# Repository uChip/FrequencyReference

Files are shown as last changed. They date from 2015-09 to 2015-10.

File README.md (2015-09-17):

Programmable Frequency Reference   
================================  

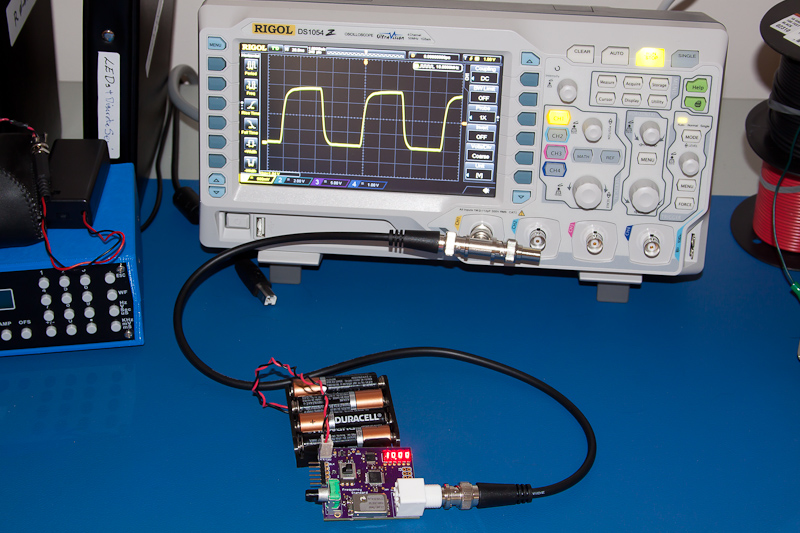
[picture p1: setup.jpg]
  
Screen capture of 10 MHz Frequency Reference signal  

This repository contains the design files and write-up for a Programmable Frequency Reference board based on the RALTRON RTX0230LC*.  The RTX0230LC is a ~1ppm accurate and stable crystal oscillator.  It is temperature compensated and tunable.  The oscillator drives the master clock of an ATmega328 microcontroller which then generates the output frequency by dividing down the master clock.  The ~2Vpp output signal is available on the BNC connector and has been impedance matched to 50 Ohms.

A set of common (and even**) frequencies from 10 MHz down to 152.6 Hz is selectable via a rotary encoder.  As each frequency is selected a representation of that frequency is shown on the display.  The following table shows the frequencies available and the displayed value.
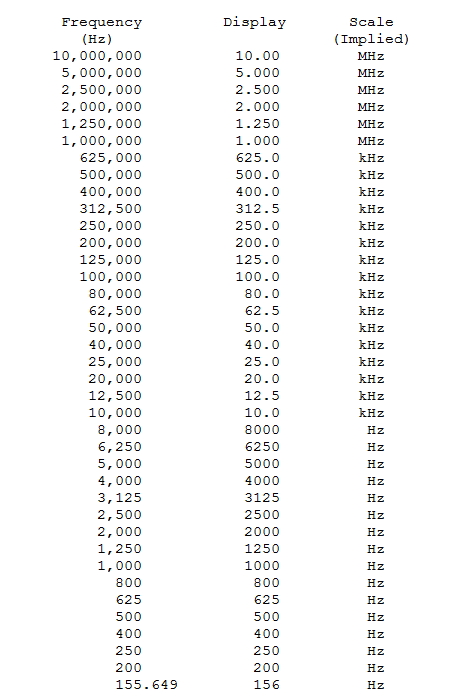
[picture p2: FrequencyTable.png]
Common Frequency Table


NOTE that the display is NOT a measure of the produced frequency.

Within the microcontroller the TCXO clock drives Timer/Counter1.  The Timer/Counter1 is configured to count up until the value matches that in Output Compare Register A (OCR1A) at which point the counter is reset to zero and the output pin OC1A is toggled.  The values for OCR1A are selected from a table when the encoder knob is turned.

Alternatively, pressing the encoder knob will change the mode of the software and instead of choosing from a table, an integer divisor value (0 to 65535) is shown on the display and sent to OCR1A.  The count is incremented or decremented by turning the encoder knob.  The output frequency will be a function of the integer value as follows:

F_OUT = F_CPU / ( 2 * ( OCR1A + 1 ))

Pressing the encoder knob again returns the software to the common frequency mode.

The mode, table value and divisor can also be sent to the microcontroller over USB through the board's FTDI interface.  For details on USB programming, see the document USB_Programming.pdf in this repo.

The firmware folder contains an Arduino sketch and associated library that is source for the microcontroller code.

The next revision of the board will be designed to accomodate other oscillators should the RTX0230LC become unavailable or if even higher precision and stability are required.  Also, the firmware can be used on an "off the shelf" Arduino Uno to create a functional but less accurate frequency generator.  See the file VariationsOnATheme.pdf in this repo for more details.

NOTES  

\* The RALTRON RTX0230LC is a surplus part cheaply available (~$5.50 for 5 pieces at the time of this writing) on ebay. http://www.ebay.com/sch/i.html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

** Mostly.  All but the last are even numbered divisions of the master clock.  The last is the highest possible divisor, 65535, generating the lowest possible*** frequency.

*** Not really.  The firmware configures the timer/counter to be driven by the system clock.  By reconfiguring, the timer/counter could instead be driven by a prescaled clock.  Prescaler values are 1, 8, 64, 256, 1024, allowing for much lower frequency generation if needed.  The prescaler value can be set via the USB interface.

## Order PCBs  

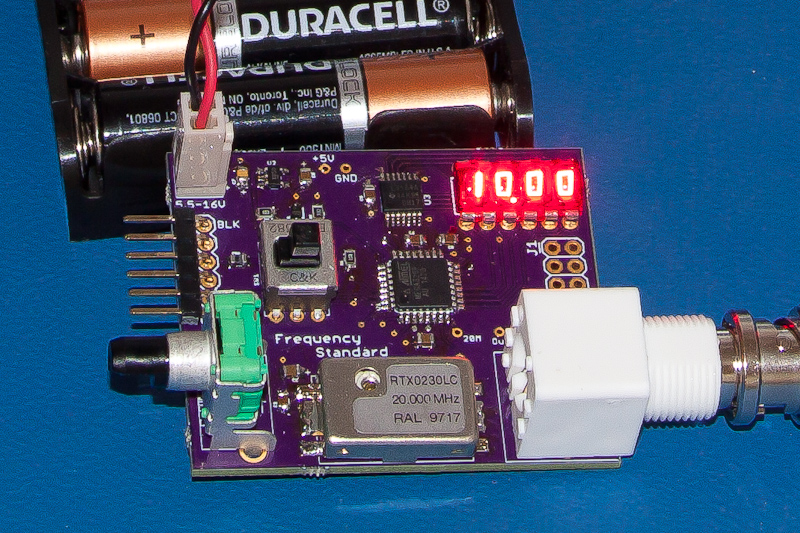
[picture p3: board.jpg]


If there is sufficient interest I will build and calibrate a batch of these to sell.  If you would like one, please contact me.

You can order this PCB directly from OSH Park.  Click on the following link.  
  * Programmable Frequency Reference - https://oshpark.com/shared_projects/a4BIq3K5 

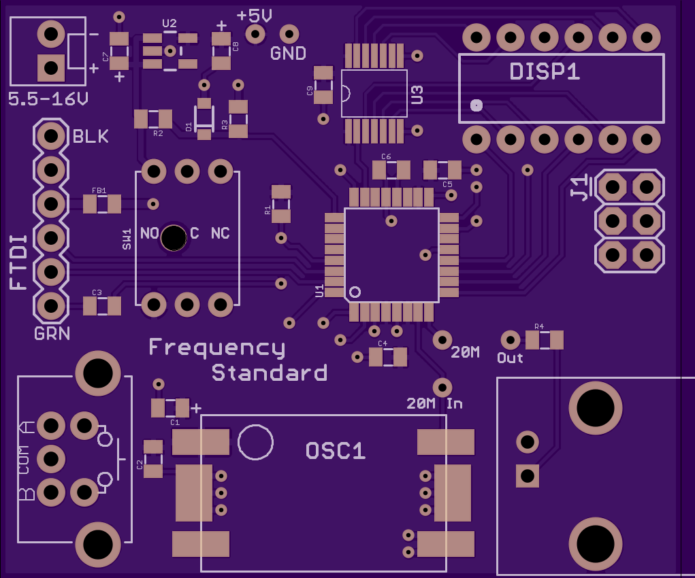
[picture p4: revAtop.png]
PCB Top


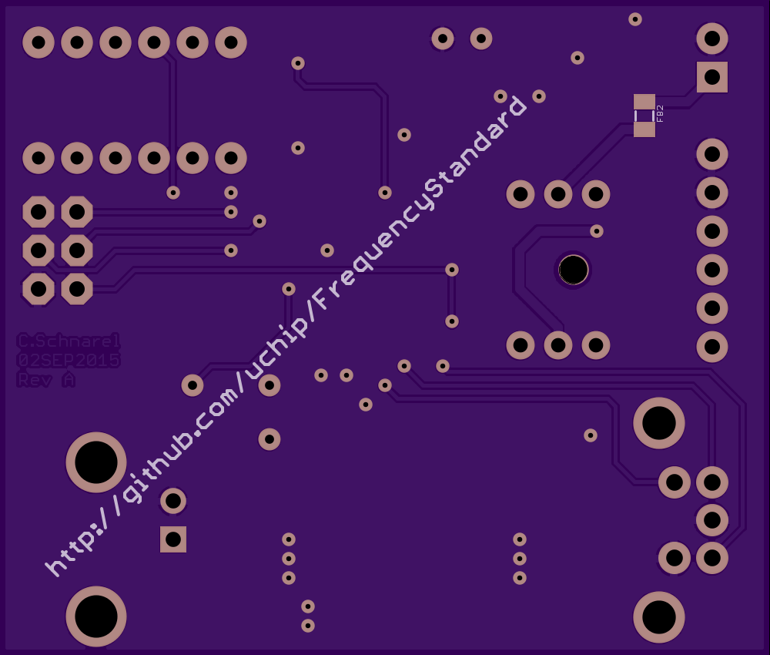
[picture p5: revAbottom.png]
PCB Bottom


See the Bill of Materials (BOM) file for a parts list.  

## Status  
  * Rev A PCB and firmware have been tested to be functional. Rev A is an earlier branch in this repo.  The design has since moved on to add support for other oscillators.
  * Rev B Not yet complete or tested.

## File Formats  

Hardware design files are in "CadSoft EAGLE PCB Design Software" .brd and .sch formats.  A free version of the software can be downloaded from www.cadsoftusa.com. 

The example code is in Arduino .ino format (text).  A free version of the Arduino software can be downloaded from www.arduino.cc. 

Documentation is generally done in Wordpad .rtf and Excel .xlsx.

Viewable versions of layout, schematic and documentation are generally available in common formats such as .pdf, .png, .jpg, .txt, etc.   

## Attributions

While the board layout, circuit design and microcontroller firmware are all my own, the idea for this project grew out of the 3 Dollar Precision Frequency Standard thread started by paulie on EEVBlog forum  http://www.eevblog.com/forum/projects/3-dollar-precision-frequency-standard/  

## Distribution License  

License:
<br /><span xmlns:dct="http://purl.org/dc/terms/" property="dct:title">Programmable Frequency Reference</span> by <a xmlns:cc="http://creativecommons.org/ns#" href="https://github.com/uChip/FrequencyReference" property="cc:attributionName" rel="cc:attributionURL">C.Schnarel</a> is licensed under a <a rel="license" href="http://creativecommons.org/licenses/by-sa/4.0/">Creative Commons Attribution-ShareAlike 4.0 International License</a>.

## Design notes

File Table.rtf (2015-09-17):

Frequency Display Scale
(Hz) (Implied)
10,000,000 10.00 MHz
5,000,000 5.000 MHz
2,500,000 2.500 MHz
2,000,000 2.000 MHz
1,250,000 1.250 MHz
1,000,000 1.000 MHz
625,000 625.0 kHz
500,000 500.0 kHz
400,000 400.0 kHz
312,500 312.5 kHz
250,000 250.0 kHz
200,000 200.0 kHz
125,000 125.0 kHz
100,000 100.0 kHz
80,000 80.0 kHz
62,500 62.5 kHz
50,000 50.0 kHz
40,000 40.0 kHz
25,000 25.0 kHz
20,000 20.0 kHz
12,500 12.5 kHz
10,000 10.0 kHz
8,000 8000 Hz
6,250 6250 Hz
5,000 5000 Hz
4,000 4000 Hz
3,125 3125 Hz
2,500 2500 Hz
2,000 2000 Hz
1,250 1250 Hz
1,000 1000 Hz
800 800 Hz
625 625 Hz
500 500 Hz
400 400 Hz
250 250 Hz
200 200 Hz
155.649 156 Hz

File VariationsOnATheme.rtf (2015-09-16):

Alternatives and Variations

The Frequency Reference is made up of just a few functional blocks connected as shown below.

The heart of the device is the precision oscillator. The final output frequency is an integer division of the oscillator. The output block in this case is merely a resistor and a BNC connector. The divider circuit is an integrated peripheral of the controller. Once the divider is set up by the controller, it operates independently. The controller can change the setup of the divider at any time and does so in response to input.** Input can either be the rotary encoder / switch or the USB/serial port. Note that the controller sends setup information to the divider but does not ever read anything back. The display is driven by the controller and does not rely on the state of the divider.

The precision and stability of the entire circuit depends on the oscillator. The nominal design uses the RTX-230 which actually has pretty good stability considering it costs around a dollar. To make a better reference, choose an oscillator with better specs. Rev-B of the circuit board retains support for the RTX-230 but also allows for oscillators with very good published specifications for, granted, a lot more money. Because most of the circuit is digital, the overall precision of the device increases with the better oscillator. That is, the fact that the rest of the circuit is cheap does not mean that it degrades the better oscillator performance.

Here are a few examples of alternate oscillator parts with increasing accuracy, stability and price. The Raltron part is also shown for comparison. Any of these will work with the Frequency Reference circuit, but not with the Rev-A PCB. I will work to include support for as many of these as I can on the Rev-B PCB (although due to cost, I will not be able to test them all).

Type | MFR | Part # | Initial (+-)ppm | Temp (+-)ppb | Voltage (+-)ppb | Aging (+-)ppb/day | Inclusive (+-)ppm | Over(yrs) | Temp Range | Cost | Supply Voltage | Supply Current max mA
TCXO | Raltron | RTX-230 | Adj | 2500 | 300 | | 1 | 1 | -30-75 | $ 1.10 | 5 | 2
TCXO | Connor-Winfield | M100F-020.0M | 1 | 100 | 200 | 40 | 3.0 | 20 | 0-70 | $ 23.70 | 3.3 | 3.3
TCXO | Connor-Winfield | DOT050F-020.0M | 1 | 50 | 20 | 10 | 4.6 | 15 | 0-70 | $ 39.38 | 3.3 | 10
OCXO | Connor-Winfield | DOC020F-020.0M | 1 | 20 | 20 | 10 | 4.6 | 20 | 0-70 | $ 54.33 | 3.3 | 758
OCXO | Connor-Winfield | OH100-70503CF-020.0M | 0.1 | 5 | 2 | 1 | 0.3 | 20 | -20-70 | $ 115.50 | 3.3 | 970
Prices are from Digi-Key

**Changing frequencies is not phase synchronous. When the change occurs, the clock is stopped, the new divisor (or prescaler) value is programmed, the count is zero’d, then the clock is restarted.

Other Frequencies

The board and software do not really know what frequency they are running at. You could therefore substitute oscillators of other frequencies. The output frequency would scale but otherwise everything would work the same. The maximum frequency oscillator is in the neighborhood of 20MHz. Higher frequencies would be over-clocking the controller, but it will still work up to a point. Lower frequencies are also okay, however the display might start to flicker as the lower clock means a slower controller. The flicker can be fixed by changing the delays in the software. In either case baud rates will need to be scaled for correct serial communications.

As an example, the exact same (source) code will run on a SparkFun Redboard (Arduino Uno clone) which runs at 16MHz and derives its clock from a ceramic resonator rather than a crystal. The software works fine (with degraded accuracy, tempco and jitter), however the frequency table shifts down to the following.

Frequency Display Scale
(Hz) (Implied)
8,000,000 10.00 MHz
4,000,000 5.000 MHz
2,000,000 2.500 MHz
1,600,000 2.000 MHz
1,000,000 1.250 MHz
800,000 1.000 MHz
400,000 500.0 kHz
320,000 400.0 kHz
250,000 312.5 kHz
200,000 250.0 kHz
160,000 200.0 kHz
100,000 125.0 kHz
80,000 100.0 kHz
64,000 80.0 kHz
40,000 50.0 kHz
32,000 40.0 kHz
20,000 25.0 kHz
16,000 20.0 kHz
10,000 12.5 kHz
8,000 10.0 kHz
6,400 8000 Hz
4,000 5000 Hz
3,200 4000 Hz
2,500 3125 Hz
2,000 2500 Hz
1,600 2000 Hz
1,000 1250 Hz
800 1000 Hz
640 800 Hz
400 500 Hz
320 400 Hz
200 250 Hz
160 200 Hz
122.07 153 Hz

Note that the display does not change since it is unrelated to the actual frequency. You can make the display correct (sort of, without more work, decimals will be wrong sometimes) by substituting the following data table in the source.

static uint16_t dispFreq[] = {
8000, // 8,000,000
4000, // 4,000,000
2000, // 2,000,000
1600, // 1,600,000
1000, // 1,000,000
8000, // 800,000
4000, // 400,000
3200, // 320,000
2500, // 250,000
2000, // 200,000
1600, // 160,000
1000, // 100,000
800, // 80,000
640, // 64,000
400, // 40,000
320, // 32,000
200, // 20,000
160, // 16,000
100, // 10,000
8000, // 8,000
6400, // 6,400
4000, // 4,000
3200, // 3,200
2500, // 2,500
2000, // 2,000
1600, // 1,600
1000, // 1,000
800, // 800
640, // 640
400, // 400
320, // 320
200, // 200
160, // 160
122 // 122
};

By further adjusting these tables, oscillators of other frequencies can be accommodated.

Cost

The original intent of the “$3 Frequency Standard” has been compromised by the cost of the rotary encoder, PCB and display circuitry. Still the entire cost remains under $22 total, which is not too bad in my opinion. Here is a cost breakdown of the BOM.

If this is too expensive for you, the cost can be lowered by not populating various parts of the PCB.

You can eliminate the display by not populating DISP1, U3 and C9. The device will operate the same. You can use an external frequency counter to see where you are at.

The device will also operate if you do not populate the rotary encoder. Then user input will need to be supplied over the serial interface.

You can choose to not populate the power switch. Either wire in a cheaper switch or just jumper the NO to C pins on each side. You can choose to not populate the power input connector by just soldering wires in directly (or by powering only off of USB through the FTDI connector). If you only power from USB/FTDI you can choose to not populate the voltage regulator, U2, and associated components, JP1, C7, D1, FB2, R2, & R3.

If you exercise all of these, the cost comes out to be $14.37. You can squeeze out a few more dollars if you forego things like the BNC connector and use cheaper components, but the output signal will suffer.

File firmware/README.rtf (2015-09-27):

Firmware Build Notes
WARNING: THE INSTRUCTIONS BELOW HAVE THE POTENTIAL TO CORRUPT YOUR ARDUINO IDE INSTALLATION. PROCEED AT YOUR OWN PERIL! OF COURSE, IF YOU REALLY MESS THINGS UP YOU CAN ALWAYS UNINSTALL AND REINSTALL THE IDE.
ANOTHER WARNING: I MANAGED TO BRICK THE MICROCONTROLLER EXPERIMENTING WITH THE INSTRUCTIONS BELOW. SEE “Unbricking the Microcontroller” BELOW FOR MORE DETAILS.
NOTE: These instructions were developed and tested using the Arduino 1.6.4 IDE. I have no idea whether they will work for other versions of the IDE.

The Frequency Reference firmware is built using the Arduino IDE, however there are a couple of complications. These complications arise because Arduino generally expects the ATmega328p to use a 16 MHz clock. For this project the clock is set to 20 MHz. That means that things like baud rate and timing ( millis(), micros(), delay(), delayMicroseconds() ) will not work as expected.
The IDE accommodates other clock speeds using the parameters defined in the boards.txt file. This file specifies the clock speed for each type of board. Unfortunately, none of them have a 20 MHz clock. What we need to do is define a new board type with a 20 MHz clock. Since the hardware for this project looks a lot like an Arduino UNO we will make a copy of the UNO parameters and call it Arduino UNO-20.
In the boards.txt file find this:
uno.name=Arduino Uno
uno.vid.0=0x2341
uno.pid.0=0x0043
uno.vid.1=0x2341
uno.pid.1=0x0001
uno.vid.2=0x2A03
uno.pid.2=0x0043

uno.upload.tool=avrdude
uno.upload.protocol=arduino
uno.upload.maximum_size=32256
uno.upload.maximum_data_size=2048
uno.upload.speed=115200

uno.bootloader.tool=avrdude
uno.bootloader.low_fuses=0xFF
uno.bootloader.high_fuses=0xDE
uno.bootloader.extended_fuses=0x05
uno.bootloader.unlock_bits=0x3F
uno.bootloader.lock_bits=0x0F
uno.bootloader.file=optiboot/optiboot_atmega328.hex

uno.build.mcu=atmega328p
uno.build.f_cpu=16000000L
uno.build.board=AVR_UNO
uno.build.core=arduino
uno.build.variant=standard

Duplicate the section, and then modify the duplicate so it looks like this:

uno20.name=Arduino Uno-20

uno20.vid.0=0x2341
uno20.pid.0=0x0043
uno20.vid.1=0x2341
uno20.pid.1=0x0001
uno20.vid.2=0x2A03
uno20.pid.2=0x0043

uno20.upload.tool=avrdude
uno20.upload.protocol=arduino
uno20.upload.maximum_size=32256
uno20.upload.maximum_data_size=2048
uno20.upload.speed=115200

uno20.bootloader.tool=avrdude
uno20.bootloader.low_fuses=0xFF
uno20.bootloader.high_fuses=0xDE
uno20.bootloader.extended_fuses=0x05
uno20.bootloader.unlock_bits=0x3F
uno20.bootloader.lock_bits=0x0F
uno20.bootloader.file=optiboot/optiboot_atmega328.hex

uno20.build.mcu=atmega328p
uno20.build.f_cpu=20000000L
uno20.build.board=AVR_UNO
uno20.build.core=arduino
uno20.build.variant=standard

I have highlighted the differences between the two sections. Once you have made the changes and saved the file back to its original location, you need to restart the IDE for the change to take effect.

If all goes well, the new Arduino UNO-20 should be available in the list of boards under the Tools->Board: menu. Choose it for this project hardware. This one change actually gets us 95% of what we want. It allows the baud rate to be set correctly and the timing functions to be mostly correct. (There's more than appears going on here, but for now just accept that it works for this application with Arduino IDE 1.6.4 and presumably newer.)
Because there is no bootloader in the ATmega328p as it ships from the factory, you will need to program it the first time using an ISP. I use the AVR Pocket Programmer from SparkFun plus the pogo-pin adapter. It's pretty cheap and it works well for me. After choosing the board, Arduino UNO-20 under Tools->Board:, and the appropriate programmer, USBtinyISP under Tools->Programmer: (for the SparkFun AVR Pocket Programmer), burn the bootloader with the command Tools->Burn Bootloader then upload the application with the command File->Upload Using Programmer.
After uploading the application with the ISP, the Frequency Reference is fully functional. You can connect to it using a terminal emulator (or the Serial Monitor in the Arduino IDE) to send commands and see status messages from the device. However there is one thing that you cannot do, that is reprogram the device using the serial port. If you have no desire to modify the software or you are comfortable using the ISP every time, then you can stop here.
Going Further
The reason why you cannot upload over serial is that the bootloader specified above was built using the assumption of a 16 MHz clock. To make serial programming work, you need a new bootloader that has been built for 20 MHz. You can find a precompiled bootloader for 20 MHz here: http://www.grozeaion.com/electronics/arduino/155-overclocking-atmega328p
On that page you will find a lot of instructions for building the bootloader, but about half-way down the page there are links to versions that have been precompiled for 20 and 24 MHz. Since the author does not highlight the links, they can be hard to find. Here is a direct link to the file: http://www.grozeaion.com/Electronics/optiboot.zip
The author explains how to install them, but to simplify: Find the optiboot_atmega328__20MHz.hex file in the optiboot.zip file. Copy that .hex file into the bootloaders/optiboot folder (near where you found the boards.txt file). There will already be an optiboot_atmega328.hex file in the correct folder.
Now that we have the 20 MHz bootloader, we have to tell the IDE to use it for this board. The author of the bootloader has a number of suggested changes to the boards.txt file; however I have found that these two changes are enough.
In boards.txt change this:
uno20.upload.speed=115200

to this: (changes highlighted)
uno20.upload.speed=250000
and this:
uno20.bootloader.file=optiboot/optiboot_atmega328.hex

to this: (changes highlighted)
uno20.bootloader.file=optiboot/optiboot_atmega328__20MHz.hex

Make sure you change uno20 and NOT uno! Again, you will need to save the boards.txt file back to the original location and restart the IDE for the changes to take effect. Then you will need to reburn the bootloader with the Tools->Burn Bootloader menu item.
That's it. With that change and reburning (or burning it for the first time if you had not previously done so) the bootloader the Frequency Reference will be able to be programmed over serial.
Unbricking the Microcontroller
I wanted to see if I could get a better 20 MHz output from the microcontroller. The flags program the microcontroller to expect a crystal on the XTAL1 and XTAL2 pins. Changing the flags you can supply an external clock on XTAL1 instead. I was hoping when you did that the clock would be forwarded out on XTAL2 (the “20M” test point) and with luck it would be buffered. So I tried different combinations of flags to try to achieve this.
Instead, what happened was when I programmed the flags for an external clock EVERYTHING stopped working. I could no longer load a sketch via serial. I could no longer load a sketch via the ISP. Even programming the bootloader failed. The simple reason for this is that the microcontroller was no longer getting ANY clock. Normally an unprogrammed ATmega comes with the flags set so that the microcontroller uses an internally generated clock, then loading the bootloader reprograms the flags to expect a crystal. The output of the RTX-230 is a clipped sine wave of about 2 volts. With the microcontroller expecting a crystal, the 2V signal works, but when you program the flags for external clock the 2V signal does not meet the threshold requirements so nothing works. Oops.
To unbrick the microcontroller I soldered wires to the test points marked “20M In” and “GND”. I then connected the wires to a function generator generating a 900 kHz square wave (max frequency of the only other function generator I have available) with 4.5V amplitude. Then I used the ISP to burn the bootloader with the flags set back to the values shown in the example above. The bootloader burned without error so I tried loading the sketch using the ISP. This also worked without errors, so I removed the programmer and the function generator and applied power. Everything is back to working.
With the flags programmed to expect a crystal there is a 20 MHz signal on the “20M” test point, but it is driven so lightly that even putting a scope probe on it locks up the whole board. I’m sure that buffering the RTX-230 before driving the microcontroller would work with the flags set for external clock, but I still don’t know that the clock would be output on XTAL2. I’m interested in moving on to other projects, so I’m going to leave well enough alone. Give it a try if you are interested, but be careful. You have been warned!

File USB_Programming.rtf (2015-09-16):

Controlling the Frequency Reference Remotely Over USB

The Frequency Reference board includes an FTDI interface. By using a USB to FTDI adapter you can send commands to the Frequency Reference to choose a frequency from the common frequency table, or set the mode, the divisor and the prescaler value. All commands are ASCII text so they can be sent from a terminal emulator. Alternatively, you could create an application with a nice "Front Panel" or that controls the Frequency Reference dynamically.
The FR expects to communicate at 8-N-1 bits at a baud rate of 9600.
The Frequency Reference is controlled by messages in the format “#PCNNNNN.” defined as follows.

- ‘#’ start of message. If the first character has any other value the entire message will be ignored.

- P: a single ASCII character denoting message type. The initial value is ‘b’. All undefined values will cause the message to be ignored.

- C: a single ASCII character indicating the command. All undefined values will cause the message to be ignored. Valid values are;
‘T’ – choose a frequency value from the table based on NNNNN. (Sets mode to TABLE_VALUES.)
‘D’ – set the divisor to NNNNN. (Sets mode to DIVISOR,)
‘P’ – set the prescaler based on NNNNN. (See NOTE.)
‘M’ – set the mode based on NNNNN. (Table index / divisor are left unchanged.)
NOTE: Setting the prescaler to a value other than 1 will cause the display to read incorrectly. Setting the prescaler persists until another set prescaler command or the unit is reset (turned off and on).

- NNNNN: a five-digit decimal number. Non-digit characters or incorrect number of characters will cause the message to be ignored. Valid number ranges are as follows. Invalid numbers will cause the message to be ignored.
‘T’ – NNNNN range is 0 to 37.
‘D’ – NNNNN range is 0 to 65535.
‘P’ – NNNNN range is 0 to 5.
NNNNN = 0; turn the divider off (no output)
NNNNN = 1; prescaler set to 1
NNNNN = 2; prescaler set to 8
NNNNN = 3; prescaler set to 64
NNNNN = 4; prescaler set to 256
NNNNN = 5; prescaler set to 1024
‘M’ – NNNNN range is 0 to 1.
NNNNN = 0; set mode to table (rotary picks from table)
NNNNN = 1; set mode to divisor (rotary increments/decrements divisor directly)

- ‘.’ end of message. If this character is omitted or has any other value the entire message will be ignored.

Examples
Set the frequency to 50kHz via the table: “#bT00014.”
Set the frequency to 2.5MHz via the divisor (divisor = 20,000,000/(2*2,500,000)-1 = 3): “#bD00003.”
Set the frequency to 12,500 Hz via the divisor (divisor = 20,000,000/(2*12,500)-1 = 799): “#bD00799.”
Set the frequency to 12,345 Hz via the divisor (divisor = 20,000,000/(2*12,345)-1 = 809): “#bD00809.” Actual frequency will be 20,000,000/(2*(809+1)) = 12,345.679 Hz
Set the prescaler to 1024: “#bP00004.”

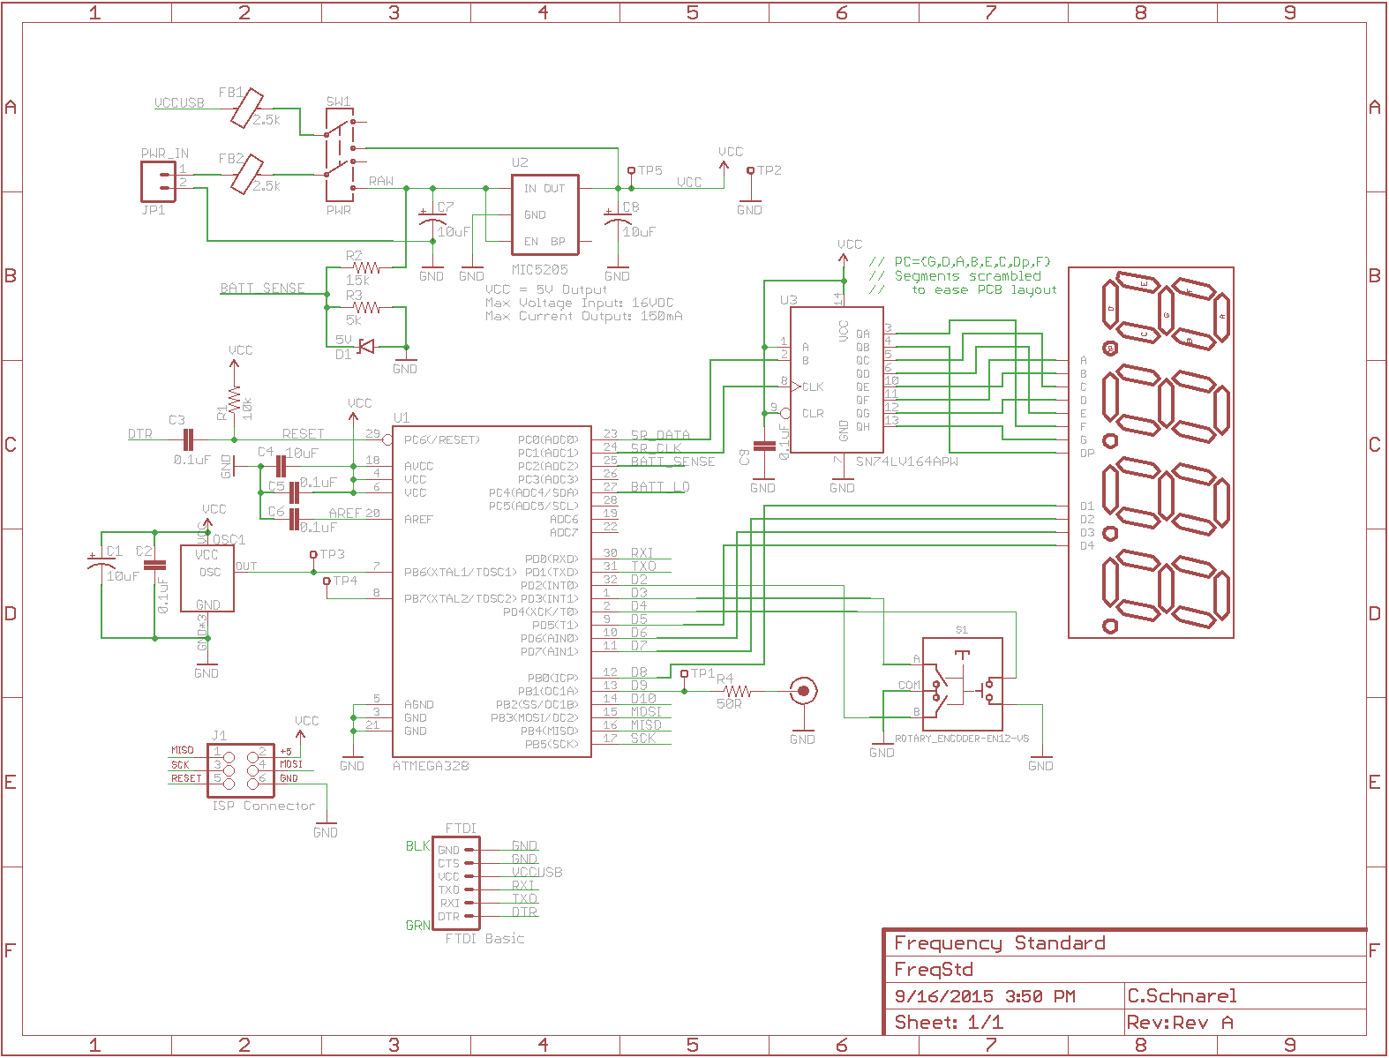
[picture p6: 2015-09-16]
RevAschematic.png

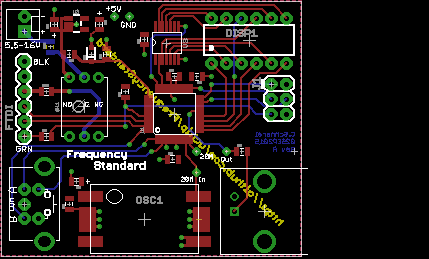
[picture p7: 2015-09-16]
RevAlayout.png

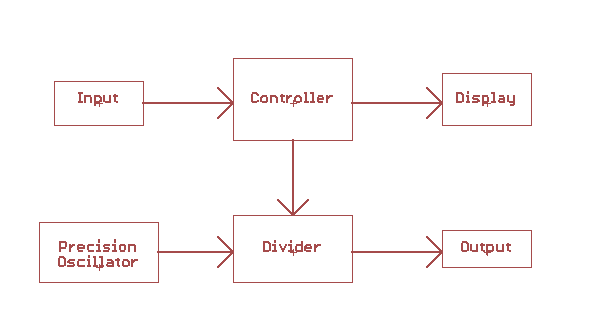
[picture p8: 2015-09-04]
diagram.png

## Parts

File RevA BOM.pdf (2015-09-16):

Qty Value | Device | Parts | Source | Part # | Cost | Description
1 20.000000MHz | TCXO-RTXO230LC | OSC1 | eBay | | $ 1.10 | Available here: http://www.ebay.com/itm/RALTRON-RTX0230LC-20-000MHz- TCXO-Oscillator-NEW-5-PKG-/191356909770
1 | PCB | OSHPark a4BIq3K5 | $ 5.67
5 0.1uF | Capacitor | C2, C3, C5, C6, C9 Digi-Key | 399-1171-1-ND | $ 0.27 Capacitor
2 10k | Resistor | R1, R2 | Digi-Key | 311-10.0KLRCT-ND | $ 0.01 Resistor
1 10uF | Capacitor | C4 | Digi-Key | 587-2225-1-ND | $ 0.26 Capacitor
3 10uF | Capacitor | C1, C7, C8 | Digi-Key | 478-8456-1-ND | $ 1.40
2 2.5k | FERRITE_BEAD | FB1, FB2 | Digi-Key | 1276-6377-1-ND | $ 0.20 Ferrite Bead, value is Resistance@Frequency (typ 100 MHz)
1 49.9R | Resistor | R4 | Digi-Key | 311-49.9CRCT-ND | $ 0.14 Resistor
1 5V | Diode, zener, 4.7V | D1 | Digi-Key | 568-6286-1-ND | $ 0.01 Zener Diode
1 3.3k | Resistor | R3 | Digi-Key | 311-3.30KCRCT-ND | $ 0.01 Resistor
1 ATMEGA328P | ATMEGA328P | U1 | Digi-Key | ATMEGA328P-AURCT-ND $ 3.70
1 BNC_RIGHT-ANGLE | BNC connector | J2 | Digi-Key | A97553-ND | $ 2.03 TE Connectivity AMP Connectors 1-1337543-0, Digi-Key #A97553-ND
1 FTDI Basic | pins | FTDI | SparkFun PRT-00116 | $ 0.23 break-away pins straight or right angle (6-pins)
1 HP_DISPLAY | HP_DISPLAY | DISP1 | SparkFun COM-12710 | $ 2.95 SparkFun COM-12710
1 MIC5205 | Voltage Regulator, LDO | U2 | Digi-Key | 576-1262-1-ND | $ 0.62 Voltage Regulator LDO
1 PWR | SWITCH,BUTTON,ROUND,7MM | SW1 | Mouser | 611-PVB6THTEE300NS | $ 1.33 Switch, DPDT, PTH, 200mA, 14V, 7mm ROUND CAP
1 PWR_IN | Connector | JP1 | SparkFun PRT-08233 | $ 0.45 Standard 2-pin 0.1 header. Use with"
1 Switch | ROTARY_ENCODER | S1 | Digi-Key | 987-1198-ND | $ 1.11 Rotary Encoder with push-button switch.
1 SN74LV164APW | SN74LV164APW | U3 | Digi-Key | 296-3788-1-ND | $ 0.46 8-BIT SERIAL-IN PARALLEL-OUT SHIFT REGISTER with clear

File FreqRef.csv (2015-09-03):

Qty | Value | Device | Package | Parts | Description
1 |  | TCXO-RTXO230LC | TCXO | OSC1 | Available here: http://www.ebay.com/itm/RALTRON-RTX0230LC-20-000MHz-TCXO-Oscillator-NEW-5-PKG-/191356909770
5 | 0.1uF | CAP0805 | 0805 | C2, C3, C5, C6, C9 | Capacitor
1 | 10k | RESISTOR0805-RES | 0805 | R1 | Resistor
1 | 10uF | CAP0805 | 0805 | C4 | Capacitor
3 | 10uF | CAP_POL0805 | 0805-POL | C1, C7, C8
1 | 15k | RESISTOR0805-RES | 0805 | R2 | Resistor
2 | 2.5k | FERRITE_BEAD_0805 | 0805 | FB1, FB2 | Ferrite Bead, value is Resistance@Frequency (typ 100 MHz)
1 | 50R | RESISTOR0805-RES | 0805 | R4 | Resistor
1 | 5V | DIODE-ZENER3.3V | SOD-323 | D1 | Zener Diode
1 | 5k | RESISTOR0805-RES | 0805 | R3 | Resistor
1 | ATMEGA328 | ATMEGA168 | TQFP32-08 | U1
1 | BNC_RIGHT-ANGLE | BNC_RIGHT-ANGLE | BNC-RIGHT-ANGLE | J2 | TE Connectivity AMP Connectors 1-1337543-0, Digi-Key #A97553-ND
1 | FRAME_LTR_CU_MARK | FRAME_LTR_CU_MARK | FR-LTR-ON-PCB | FRAME1 | This frame is sized for an 8.5x11 page with a 0.25" margin. It also places a name, datecode and revision mark in the bottom copper layer of the PCB."
1 | FTDI Basic | ARDUINO_SERIAL_PROGRAMPTH | 1X06 | FTDI
1 | HP_DISPLAY | HP_DISPLAY | DIL12 | DISP1
1 | ISP Connector | AVR_SPI_PRG_6PTH | 2X3 | J1 | AVR ISP 6 Pin
1 | MIC5205 | V_REG_LDOSMD | SOT23-5 | U2 | Voltage Regulator LDO
1 | PWR | SWITCH,BUTTON,ROUND,7MM | 8X10_BUTTON_ROUND | SW1 | BETA! SB0003 - Switch, DPDT, PTH, 200mA, 14V, 7mm ROUND CAP
1 | PWR_IN | M02POLAR | MOLEX-1X2 | JP1 | Standard 2-pin 0.1 header. Use with"
1 | ROTARY_ENCODER-EN12-VS | ROTARY_ENCODER-EN12-VS | EN12-VS | S1 | Rotary Encoder with push-button switch.
1 | SN74LV164APW | SN74LV164APW | TSSOP-14(TI) | U3 | 8-BIT SERIAL-IN PARALLEL-OUT SHIFT REGISTER with clear
5 | TEST_POINT | TEST_POINT | BBD-VIA | TP1, TP2, TP3, TP4, TP5 | Test Point

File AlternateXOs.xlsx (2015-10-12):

Type | MFR | Part # | Initial (+-)ppm | Temp (+-)ppb | Voltage (+-)ppb | Aging (+-)ppb/day | Inclusive (+-)ppm | Over(yrs) | Temp Range | Cost | Supply Voltage | Supply Current max mA | Power W | Pkg | Output
TCXO | Raltron | RTX-230 | Adj | 2500 | 300 | 1ppm/yr |  |  | -30-75 | $1.10 | 5 | 2 |  | 12x18 | clipped sine
TCXO | Connor-Winfield | M100F-020.0M | 1 | 100 | 200 | 40 | 3.0 | 20 | 0-70 | $23.70 | 3.3 | 3.3 |  | 3.2x5 | LVCMOS
TCXO | Connor-Winfield | DOT050F-020.0M | 1 | 50 | 20 | 10 | 4.6 | 15 | 0-70 | $39.38 | 3.3 | 10 |  | 9x14 | LVCMOS
OCXO | Connor-Winfield | DOC020F-020.0M | 1 | 20 | 20 | 10 | 4.6 | 20 | 0-70 | $54.33 | 3.3 | 757.5757576 | 1.1-2.5 | 9x14 | LVCMOS
OCXO | Connor-Winfield | OH100-70503CF-020.0M | 0.1 | 5 | 2 | 1 | 0.3 | 20 | -20-70 | $115.50 | 3.3 | 969.6969697 | 1.15-3.2 | 25.4x25.4 | CMOS
OCXO | Abracon Corp | AOCJY-16.384MHZ |  | 5 | 20 | 1 | 0.5 | 10 | 0-50 | $160.80 | 5/3.3 | 1090.909091 | 3.6 | 25.4x22.1 | LVCMOS
OCXO | Connor-Winfield | OX914xS3 | 1 | 140 | 20 | 40 | 4.6 | 20 | -55-85 | $42.00 | 3.3 |  | 1.3-3.0 | 9x14 | LVCMOS
TCXO | Connor-Winfield | T200F-020.0M | 1 | 200 | 200 | 40 | 3.0 | 20 | -40-85 | $33.75 | 3.3 | 2.1 |  | 7x5 | LVCMOS
TCXO | Connor-Winfield | T100F-020.0M | 1 | 100 | 200 | 40 | 3.0 | 20 | 0-70 | $33.75 | 3.3 | 2.1 |  | 7x5 | LVCMOS
OCXO | Connor-Winfield | OX9140S3-020.0M | 1 | 140 | 200 | 40 | 4.6 | 20 | 0-70 | $37.80 | 3.3 | 909.0909091 | 1.3-3.0 | 9x14 | LVCMOS
OCXO | Connor-Winfield | OH200-61003CF-020.0M | 0.1 | 5 | 5 | 1 | 0.3 | 20 | -40-85 | $136.50 | 3.3 | 1151.515152 | 1.5-3.8 | 27x36 | CMOS
TCXO | FOX | FOX924B | 1.5 | 2500 | 300 | 1ppm/yr |  |  | -30-85 | $6.41 | 3.3 | 6 |  | 3.2x5 | HCMOS
TCXO | TXC Corp | 7N-20.000MBP-T | 2 | 280 | 100 | 1ppm/yr | 4.6 | 20 | -40-85 | $10.89 | 5 | 10 |  | 7x5 | CMOS

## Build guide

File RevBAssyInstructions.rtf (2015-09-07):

Rev_B PCB Assembly Instructions

Install only one of the following sets of oscillator related components.

Option 1:
Install - OSC1, C1 and C2
DO NOT INSTALL - OSC2, OSC3, C10, C11, C12, C13 or U5

Option 2:
Install - OSC2, C10, C11, C12, C13 and U5
DO NOT INSTALL - OSC1, OSC3, C1 or C2

Option 3:
Install - OSC3, C10, C11, C12, C13 and U5
DO NOT INSTALL - OSC1, OSC2, C1 or C2

All other components should be installed as normal.

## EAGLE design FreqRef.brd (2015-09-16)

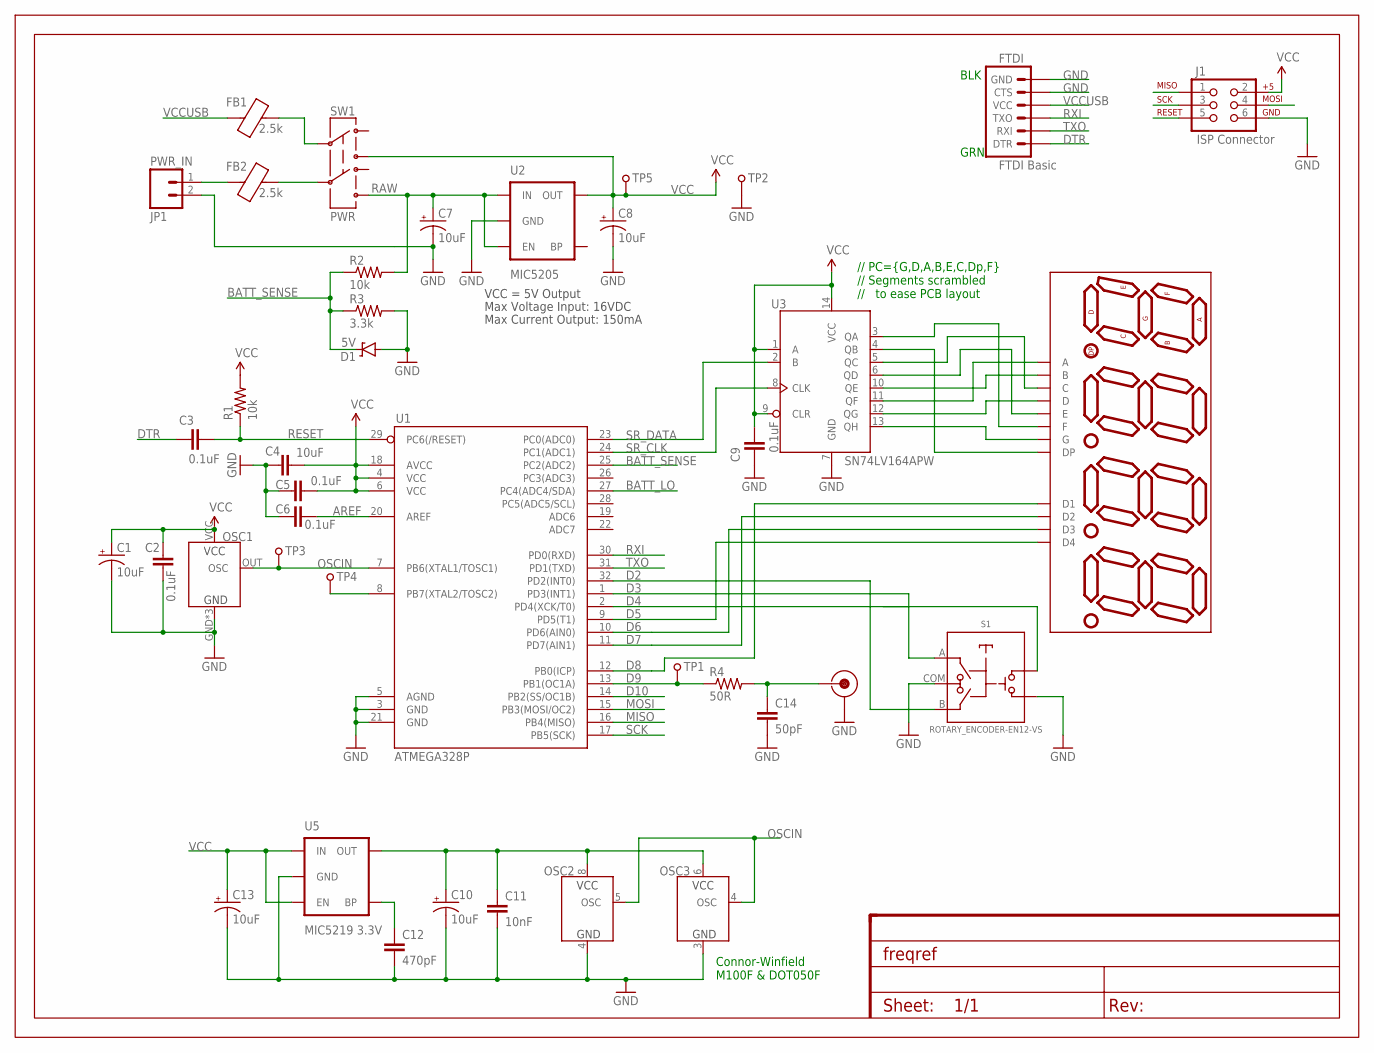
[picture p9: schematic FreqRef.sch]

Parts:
C1, C7, C8, C10, C13: 10uF; 0805-POL
C2, C3, C5, C6, C9: 0.1uF; 0805
C4: 10uF; 0805
C11: 10nF; 0805
C12: 470pF; 0805
C14: 50pF; 0805
D1: 5V; SOD-323
DISP1: HP_DISPLAY; DIL12
FB1, FB2: 2.5k; 0805
FRAME1: FRAME_LTR_CU_MARK; FR-LTR-ON-PCB
FTDI: FTDI Basic; 1X06
J1: ISP Connector; 2X3
J2: BNC_RIGHT-ANGLE; BNC-RIGHT-ANGLE
JP1: PWR_IN; MOLEX-1X2
OSC1: TCXORALTRON; TCXO
OSC2: TCXOM100; TCXO-3.2X5
OSC3: TCXODOT; TCXO-9X14
R1, R2: 10k; 0805
R3: 3.3k; 0805
R4: 50R; 0805
S1: ROTARY_ENCODER-EN12-VS; EN12-VS
SW1: PWR; 8X10_BUTTON_ROUND
TP1, TP2, TP3, TP4, TP5: TEST_POINT; BBD-VIA
U1: ATMEGA328P; TQFP32-08
U2: MIC5205; SOT23-5
U3: SN74LV164APW; TSSOP-14(TI)
U5: MIC5219 3.3V; SOT23-5

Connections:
AREF: C6.2, U1.20 (AREF)
BATT_LO: U1.27 (PC4(ADC4/SDA))
BATT_SENSE: D1.C, R2.1, R3.1, U1.25 (PC2(ADC2))
D2: S1.B, U1.32 (PD2(INT0))
D3: S1.A, U1.1 (PD3(INT1))
D4: S1.D, U1.2 (PD4(XCK/T0))
D5: DISP1.6 (D4), U1.9 (PD5(T1))
D6: DISP1.4 (D3), U1.10 (PD6(AIN0))
D7: DISP1.10 (D2), U1.11 (PD7(AIN1))
D8: DISP1.1 (D1), U1.12 (PB0(ICP))
D9: R4.1, TP1.P$1, U1.13 (PB1(OC1A))
D10: U1.14 (PB2(SS/OC1B))
DTR: C3.1, FTDI.1 (DTR)
GND: C1.2 (-), C2.1, C4.1, C5.1, C6.1, C7.2 (-), C8.2 (-), C9.1, C10.2 (-), C11.2, C12.2, C13.2 (-), C14.2, D1.A, FTDI.5 (CTS), FTDI.6 (GND), J1.6, J2.SHD, JP1.2, OSC1.GND, OSC1.SHLD1 (GND), OSC1.SHLD2 (GND), OSC2.4 (GND), OSC3.3 (GND), R3.2, S1.COM, S1.E, TP2.P$1, U1.3 (GND), U1.5 (AGND), U1.21 (GND), U2.2 (GND), U3.7 (GND), U5.2 (GND)
MISO: J1.1, U1.16 (PB4(MISO))
MOSI: J1.4, U1.15 (PB3(MOSI/OC2))
unnamed: DISP1.12 (A), U3.11 (QF)
unnamed: DISP1.11 (B), U3.10 (QE)
unnamed: DISP1.3 (C), U3.5 (QC)
unnamed: DISP1.8 (D), U3.12 (QG)
unnamed: TP4.P$1, U1.8 (PB7(XTAL2/TOSC2))
unnamed: DISP1.9 (F), U3.3 (QA)
unnamed: DISP1.7 (G), U3.13 (QH)
unnamed: DISP1.5 (DP), U3.4 (QB)
unnamed: C14.1, J2.CTR, R4.2
unnamed: DISP1.2 (E), U3.6 (QD)
unnamed: FB2.1, JP1.1
unnamed: C10.1 (+), C11.1, OSC2.8 (VCC), OSC3.6 (VCC), U5.5 (OUT)
unnamed: C12.1, U5.4 (BP)
unnamed: FB1.2, SW1.1C
OSCIN: OSC1.OUT (OSC), OSC2.5 (OSC), OSC3.4 (OSC), TP3.P$1, U1.7 (PB6(XTAL1/TOSC1))
RAW: C7.1 (+), R2.2, SW1.2NO, U2.1 (IN), U2.3 (EN)
RESET: C3.2, J1.5, R1.1, U1.29 (PC6(/RESET))
RXI: FTDI.3 (TXO), U1.30 (PD0(RXD))
SCK: J1.3, U1.17 (PB5(SCK))
SR_CLK: U1.24 (PC1(ADC1)), U3.8 (CLK)
SR_DATA: U1.23 (PC0(ADC0)), U3.2 (B)
TXO: FTDI.2 (RXI), U1.31 (PD1(TXD))
VCC: C1.1 (+), C2.2, C4.2, C5.2, C8.1 (+), C9.2, C13.1 (+), J1.2, OSC1.VCC, R1.2, SW1.1NO, TP5.P$1, U1.4 (VCC), U1.6 (VCC), U1.18 (AVCC), U2.5 (OUT), U3.1 (A), U3.9 (CLR), U3.14 (VCC), U5.1 (IN), U5.3 (EN)
VCCUSB: FB1.1, FTDI.4 (VCC)
VIN: FB2.2, SW1.2C

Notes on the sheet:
Max Voltage Input: 16VDC
Max Current Output: 150mA
VCC = 5V Output
// PC={G,D,A,B,E,C,Dp,F} // Segments scrambled // to ease PCB layout
BLK
GRN
Connor-Winfield M100F & DOT050F

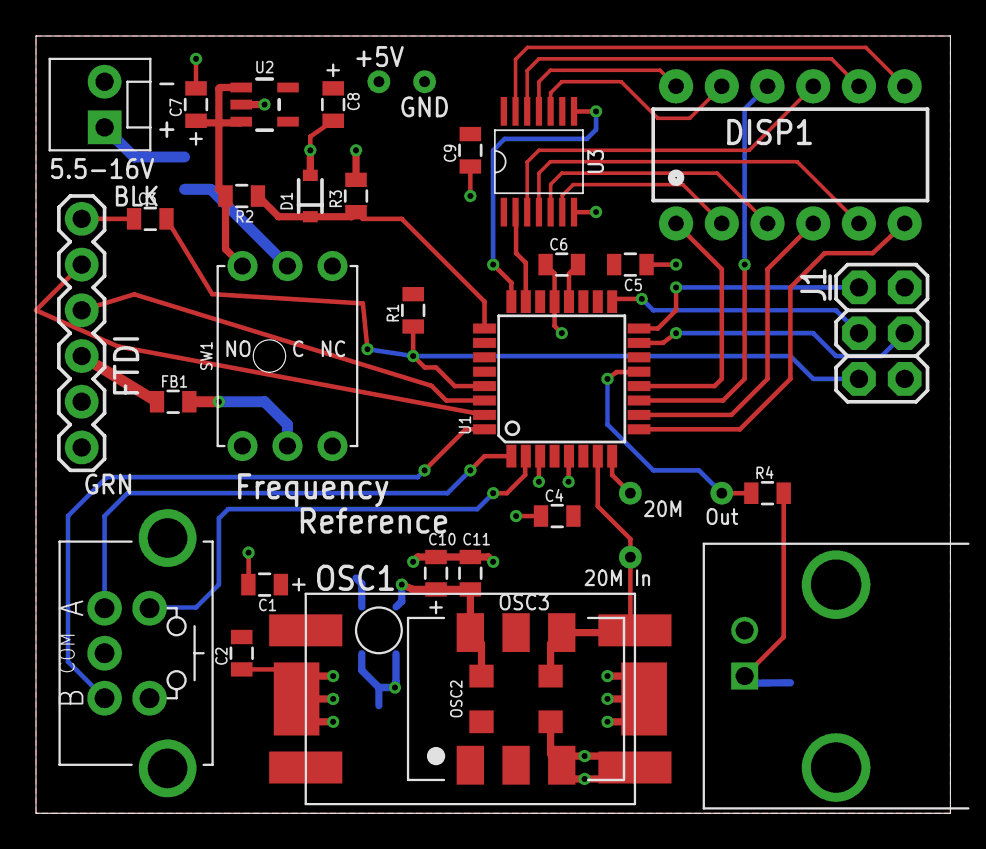
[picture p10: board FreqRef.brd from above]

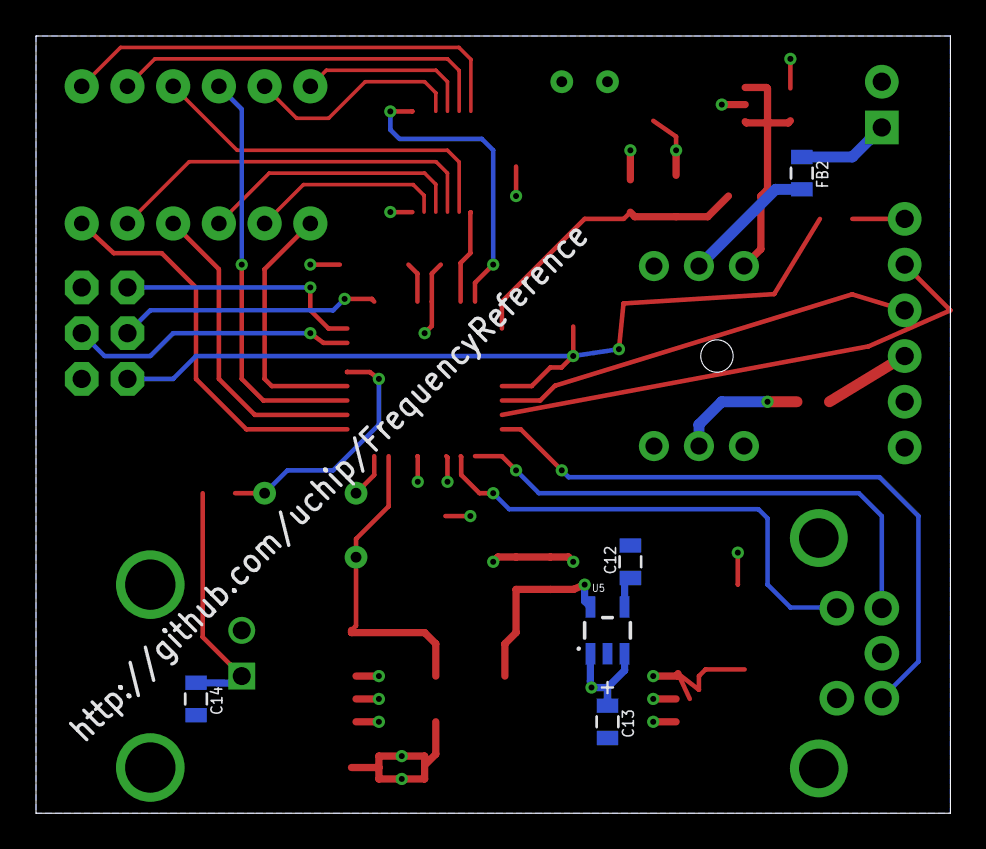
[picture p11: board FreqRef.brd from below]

Board: 2 copper layers, 50.8 x 43.2 mm, 41 parts (5 on the bottom side), 39 nets.

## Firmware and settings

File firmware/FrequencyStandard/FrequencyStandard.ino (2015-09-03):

// Include libraries this sketch will use
//#include <ProfileTimer.h>
//#include <SPI.h>
//#include <EEPROM.h>
#include <Rotary.h>
#include <Bounce.h>
#include <Timer1.h>

// Pins to drive Segment Shift Register
#define SR_DATA A0
#define SR_CLK A1

// Serial interface pins (defined in serial lib)
//#define RCV 0
//#define XMT 1

// UI Rotary Encoder w Button
#define BUTTON 4
#define DEBOUNCE_TIME 5
// Encoder interface pins (defined in rotary instantiation)
#define ROT_A 3
#define ROT_B 2

// Display digit pins
#define DIGIT_1 8
#define DIGIT_2 7
#define DIGIT_3 6
#define DIGIT_4 5

// This sets the delay time for frame rate
// The value is repeated for each of the digits on the display so 
//   frame rate = 1 / (4 * DIGIT_TIME(uS)) -> 125 Hz
#define DIGIT_TIME 2000

// Mode values
// send refVal to DAC after adding correction factor
#define TABLE_VALUES true
// send raw refVal numbers to the DAC w/o correcting
#define DIVISOR false

// PC={G,D,A,B,E,C,Dp,F}
#define DP 0x02
// Segments scrambled
//   to ease PCB layout
// Character generator for 7-segment displays
uint8_t	chargen[] = {
0b01111101,  // 0  '0'
0b00010100,  // 1  '1'
0b11111000,  // 2  '2'
0b11110100,  // 3  '3'
0b10010101,  // 4  '4'
0b11100101,  // 5  '5'
0b11101101,  // 6  '6'
0b00110100,  // 7  '7'
0b11111101,  // 8  '8'
0b11110101,  // 9  '9'
0b10111101,  // 10  'A'
0b11001101,  // 11  'B'
0b01101001,  // 12  'C'
0b11011100,  // 13  'D'
0b11101001,  // 14  'E'
0b10101001,  // 15  'F'
0b00000000   // 16  ' '
};

// Lookup table for generating common frequencies
static uint16_t commonFreq[] = {
  1,      // 10,000,000
  2,      //  5,000,000
  4,      //  2,500,000
  5,      //  2,000,000
  8,      //  1,250,000
  10,     //  1,000,000
  20,     //    500,000
  25,     //    400,000
  32,     //    312,500
  40,     //    250,000
  50,     //    200,000
  80,     //    125,000
  100,    //    100,000
  125,    //     80,000
  200,    //     50,000
  250,    //     40,000
  400,    //     25,000
  500,    //     20,000
  800,    //     12,500
  1000,   //     10,000
  1250,   //      8,000
  2000,   //      5,000
  2500,   //      4,000
  3200,   //      3,125
  4000,   //      2,500
  5000,   //      2,000
  8000,   //      1,250
  10000,  //      1,000
  12500,  //        800
  20000,  //        500
  25000,  //        400
  40000,  //        250
  50000,  //        200
  64247   //        152
};

// Lookup table for display values that go with common frequencies
static uint16_t dispFreq[] = {
  1000,      // 10,000,000
  5000,      //  5,000,000
  2500,      //  2,500,000
  2000,      //  2,000,000
  1250,      //  1,250,000
  1000,      //  1,000,000
  5000,      //    500,000
  4000,      //    400,000
  3125,      //    312,500
  2500,      //    250,000
  2000,      //    200,000
  1250,      //    125,000
  1000,      //    100,000
   800,      //     80,000
   500,      //     50,000
   400,      //     40,000
   250,      //     25,000
   200,      //     20,000
   125,      //     12,500
   100,      //     10,000
  8000,      //      8,000
  5000,      //      5,000
  4000,      //      4,000
  3125,      //      3,125
  2500,      //      2,500
  2000,      //      2,000
  1250,      //      1,250
  1000,      //      1,000
   800,      //        800
   500,      //        500
   400,      //        400
   250,      //        250
   200,      //        200
   152       //        152
};

// Battery level measurement
#define BATT_SENSE A2

// Frequency Signal Out
#define F_OUT 9

// Instantiate objects used in this project
Rotary r = Rotary(ROT_A, ROT_B);
Bounce button = Bounce(BUTTON, DEBOUNCE_TIME);
Timer1 freqDivider = Timer1();

boolean startup = true;
unsigned long startTime = 0;
uint8_t CmdArray[7];
uint8_t CmdArrayIdx = 0;
uint16_t frqIdx = 0;
uint8_t sdata = 0;
int DispBCD = 0;
boolean newVal = true;
boolean batt_lo = false;
boolean mode = TABLE_VALUES;


//-=|=-=|=-=|=-=|=-=|=-=|=-=|=-=|=-=|=-=|=-=|=-=|=-=|=-=|=-=|=-=|=-
// system startup and initialization
//-=|=-=|=-=|=-=|=-=|=-=|=-=|=-=|=-=|=-=|=-=|=-=|=-=|=-=|=-=|=-=|=-
void setup() {
  // Initialize USB interface
  Serial.begin(115200);
  //delay(2000);
  Serial.println("Reference Frequency Generator");  // set up the segment control pins

  // set up sense pins
  pinMode(BATT_SENSE, INPUT);

  // set up the button input pin
  pinMode(BUTTON, INPUT_PULLUP);
  // if button is held down at startup, stay in RAW mode (no correction applied)
  button.update();
  if(button.read() == LOW) {mode = DIVISOR;} else {mode = TABLE_VALUES;}

  // set up the display SR control pins
  pinMode(SR_DATA, OUTPUT);
  pinMode(SR_CLK, OUTPUT);
  
  // set up the digit control pins
  pinMode(DIGIT_1, OUTPUT);
  pinMode(DIGIT_2, OUTPUT);
  pinMode(DIGIT_3, OUTPUT);
  pinMode(DIGIT_4, OUTPUT);
  
  // set up frequency output pin
  pinMode(F_OUT, OUTPUT);
  
  // now do the startup dance to check the display & LEDs
  startup = true;
  startTime = millis() + 5000;
  while(startup) startLoop();
  
  // WARNING: CAN'T USE PWM (analog out) AFTER THIS
  freqDivider.begin();  // Set up counter 1 to be frequency divider
  
} // End of setup()

//-=|=-=|=-=|=-=|=-=|=-=|=-=|=-=|=-=|=-=|=-=|=-=|=-=|=-=|=-=|=-=|
// Main event loop
//   Checks for front panel and serial input
//   Checks for low battery
//   Changes the frequency output when necessary
//   Drives the display refresh/multiplexing
//-=|=-=|=-=|=-=|=-=|=-=|=-=|=-=|=-=|=-=|=-=|=-=|=-=|=-=|=-=|=-=|
void loop() {
  
  // Change the mode if the button was pressed
  // If that puts index out of range then fix it
  if(button.update()) {
    if(button.read() == HIGH) {
      mode = !mode; // if DIVISOR switch to TABLE_VALUES. if TABLE switch to DIVISOR.
      if(mode == TABLE_VALUES){
        if(frqIdx < 0) frqIdx = 33;
        if(frqIdx > 33) frqIdx = 0;
      }
      newVal = true;
    }
  }
  
  // Check the rotary and change frequency if it was turned
  unsigned char result = r.process();
  if (result) {
    result == DIR_CW ? frqIdx-- : frqIdx++;
    if(mode == TABLE_VALUES){
      if(frqIdx < 0) frqIdx = 33;
      if(frqIdx > 33) frqIdx = 0;
    }
    newVal = true;
  }

  // Check if serial data is available
  // if so, try to build a command message from the data
  while (Serial.available())
  {
    sdata = Serial.read();
    switch (sdata){
    case 35: // '#'  set DAC with correction factor
    case 33: // '!'  set DAC with no correction factor
    case 'W': // 'W' write offset values to EEPROM
    case 'R': // 'R' dump the offset table (mostly for debug)
      CmdArrayIdx = 0;
      CmdArray[CmdArrayIdx++] = sdata;
      break;
    case 10: // LF
    case 13: // CR
      CmdArray[CmdArrayIdx++] = sdata;
      if(ParseCommand())
        newVal = true;
      break;
    default:
      CmdArray[CmdArrayIdx++] = sdata;
      if(CmdArrayIdx>6) CmdArrayIdx = 6;
    }
  }  

  // If the value has changed, send 
  // the new divisor to T0 and the serial port
  if(newVal) {
    Serial.println(frqIdx);
    if(mode == TABLE_VALUES) {
      freqDivider.setDivisor(commonFreq[frqIdx]);
    }
    else freqDivider.setDivisor(frqIdx);
  }
        
  // Check for low battery
  analogRead(BATT_SENSE); // read the first time to switch to the correct input and allow it to settle
  // raw ADC count = minBatteryLevel(5.3V) * voltageDivider(1/4) / (Vref(5.0)/resolution(1024))
  //if(analogRead(BATT_SENSE) < 5.3/4/(5.0/1024)) show battery low on the display
  int charge = analogRead(BATT_SENSE);  // take another reading that should be stable
  if(charge < 362) batt_lo = true; // if battery level is under 5.3v turn the warning on
  else batt_lo = false; // otherwise turn the warning off
  if(charge < 75) batt_lo = false; // but we wouldn't be running if it was THAT low so must be USB
  
  // Refresh the display (perform one pass thru the multiplexor)
  if (batt_lo) displayRaw((uint16_t)0x02020202);
  else if(mode == TABLE_VALUES) {
    displayDecimal(dispFreq[frqIdx]);
  }
  else displayInteger(frqIdx);
  
}  // End of loop()


//-=|=-=|=-=|=-=|=-=|=-=|=-=|=-=|=-=|=-=|=-=|=-=|=-=|=-=|=-=|=-=|
// Sends data out to the display shift register
//-=|=-=|=-=|=-=|=-=|=-=|=-=|=-=|=-=|=-=|=-=|=-=|=-=|=-=|=-=|=-=|
void ShiftOut(uint8_t data) {
  digitalWrite(SR_DATA, (data & 0x80));
  digitalWrite(SR_CLK, LOW);
  digitalWrite(SR_CLK, HIGH);
  digitalWrite(SR_DATA, (data & 0x40));
  digitalWrite(SR_CLK, LOW);
  digitalWrite(SR_CLK, HIGH);
  digitalWrite(SR_DATA, (data & 0x20));
  digitalWrite(SR_CLK, LOW);
  digitalWrite(SR_CLK, HIGH);
  digitalWrite(SR_DATA, (data & 0x10));
  digitalWrite(SR_CLK, LOW);
  digitalWrite(SR_CLK, HIGH);
  digitalWrite(SR_DATA, (data & 0x08));
  digitalWrite(SR_CLK, LOW);
  digitalWrite(SR_CLK, HIGH);
  digitalWrite(SR_DATA, (data & 0x04));
  digitalWrite(SR_CLK, LOW);
  digitalWrite(SR_CLK, HIGH);
  digitalWrite(SR_DATA, (data & 0x02));
  digitalWrite(SR_CLK, LOW);
  digitalWrite(SR_CLK, HIGH);
  digitalWrite(SR_DATA, (data & 0x01));
  digitalWrite(SR_CLK, LOW);
  digitalWrite(SR_CLK, HIGH);
}  // End of ShiftOut()

//-=|=-=|=-=|=-=|=-=|=-=|=-=|=-=|=-=|=-=|=-=|=-=|=-=|=-=|=-=|=-=|=-=|=-=|=-=|
// Takes the data from the command buffer and generates
//   a new value for the Reference
//-=|=-=|=-=|=-=|=-=|=-=|=-=|=-=|=-=|=-=|=-=|=-=|=-=|=-=|=-=|=-=|=-=|=-=|=-=|
boolean ParseCommand() {

  uint8_t i = 0;
  uint16_t j = 0;
  boolean retVal = false;

  if(CmdArray[5] != 10 && CmdArray[5] != 13) {
    // Error in the command array.  Clear it and start over.
    for(i=0;i<7;i++)CmdArray[i] = 0;
    CmdArrayIdx = 0;
    return false;
  }
  
  for(i=1;i<5;i++){
    j = j*10 + (CmdArray[i]-48); // '0'==48
  }
  if(j>MAXVAL) j = MAXVAL;
  // Serial.println(j);

  switch (CmdArray[0]) {
    case 33: // '!'
      mode = RAW;
      refVal = j;
      retVal = true;
      digitalWrite(REMOTE, HIGH);
      break;
    case 35: // '#'
      mode = CORRECTED;
      refVal = j;
      retVal = true;
      digitalWrite(REMOTE, HIGH);
      break;
    case 'W':
      if(mode == RAW) {
        EEPROM.write(refVal, (byte)j);
        // Serial.print(refVal);
        // Serial.print(":");
        // Serial.println((byte)j);
      }
      retVal = false;
      break;
    case 'R':
      for(i=0; i<MAX_OFFSETS*3; i++){
        Serial.println(EEPROM.read(i), HEX);
      }
    default:
      retVal = false;
  }

  for(i=0;i<7;i++)CmdArray[i] = 0;
  CmdArrayIdx = 0;
  return retVal;
}  // End of ParseCommand()

//=====================================================================
// Do some flashy stuff to show display works and display battery level
//=====================================================================
void startLoop(){
  int16_t raw = 0;
  digitalWrite(REMOTE, HIGH);
  digitalWrite(CAL, HIGH);
  digitalWrite(BATT_LO, HIGH);
  digitalWrite(OVLD, HIGH);
  if(millis()<(startTime - 4900))      displayRaw(0x80808080); // Dp
  else if(millis()<(startTime - 4800)) displayRaw(0x08080808); // G
  else if(millis()<(startTime - 4700)) displayRaw(0x40404040); // F
  else if(millis()<(startTime - 4600)) displayRaw(0x04040404); // A
  else if(millis()<(startTime - 4500)) displayRaw(0x10101010); // B
  else if(millis()<(startTime - 4400)) displayRaw(0x01010101); // C
  else if(millis()<(startTime - 4300)) displayRaw(0x02020202); // D
  else if(millis()<(startTime - 4200)) displayRaw(0x20202020); // E
  else if(millis()<(startTime - 4100)) displayRaw(0x80808080); // Dp
  else if(millis()<(startTime - 4000)) displayRaw(0x08080808); // G
  else if(millis()<(startTime - 3900)) displayRaw(0x40404040); // F
  else if(millis()<(startTime - 3800)) displayRaw(0x04040404); // A
  else if(millis()<(startTime - 3700)) displayRaw(0x10101010); // B
  else if(millis()<(startTime - 3600)) displayRaw(0x01010101); // C
  else if(millis()<(startTime - 3500)) displayRaw(0x02020202); // D
  else if(millis()<(startTime - 3400)) displayRaw(0x20202020); // E
  else if(millis()<(startTime - 3000)) displayRaw(0xFFFFFFFF); // '8888'
  else if(millis()<(startTime - 2500)) displayRaw(0x00000000); // '    '
  else if(millis()<(startTime -  500)) {
    for(uint8_t i=0;i<10;i++){
      raw += analogRead(BATT_SENSE);
    }  
    refVal = (int16_t)((float)(raw) * .014648) * 100;
    if(refVal > 1000) displayDecimal(refVal); // Display battery voltage
    else displayRaw(0x734F7F00);  // 'USB '
  }
  else displayRaw(0x00000000); // '    '
  
  if(millis()>startTime){
    startup = false;
    refVal = 1000;
  }
}  // end startLoop()

//-=|=-=|=-=|=-=|=-=|=-=|=-=|=-=|=-=|=-=|=-=|=-=|=-=|=-=|=-=|=-=|=-=|=-=|=-=|
// Refresh the display (perform one pass thru the multiplexor)
//   Displays a 16-bit binary integer as a 4-digit decimal value
//   Decimal placed per lookup table
//   Checks for encoder input while flashing each digit
//-=|=-=|=-=|=-=|=-=|=-=|=-=|=-=|=-=|=-=|=-=|=-=|=-=|=-=|=-=|=-=|=-=|=-=|=-=|
void displayDecimal(int16_t theValue){
  // Convert the binary integer value into decimal digits
  // then multiplex the display using the digits
  DispBCD = 0;
  decimalPt = 0;
  if(frqIdx > 0 && frqIdx <= 5) decimalPt = DP;
  while(theValue >= 1000){DispBCD++; theValue-=1000;}
  ShiftOut(~(chargen[DispBCD] | decimalPt));
  digitalWrite(DIGIT_1, HIGH);
  delayMicroseconds(DIGIT_TIME);
  digitalWrite(DIGIT_1, LOW);

  unsigned char result = r.process();
  if (result) {
    result == DIR_CW ? frqIdx-- : frqIdx++;
    if(mode == TABLE_VALUES){
      if(frqIdx < 0) frqIdx = 33;
      if(frqIdx > 33) frqIdx = 0;
    }
    newVal = true;
  }

  DispBCD = 0;
  decimalPt = 0;
  if(frqIdx == 0) decimalPt = DP;
  while(theValue >= 100) {DispBCD++; theValue-=100;}
  ShiftOut(~(chargen[DispBCD] | decimalPt));
  digitalWrite(DIGIT_2, HIGH);
  delayMicroseconds(DIGIT_TIME);
  digitalWrite(DIGIT_2, LOW);

  if (result) {
    result == DIR_CW ? frqIdx-- : frqIdx++;
    if(mode == TABLE_VALUES){
      if(frqIdx < 0) frqIdx = 33;
      if(frqIdx > 33) frqIdx = 0;
    }
    newVal = true;
  }

  DispBCD = 0;
  decimalPt = 0;
  if(frqIdx > 5 && frqIdx <= 19) decimalPt = DP;
  while(theValue >= 10)  {DispBCD++; theValue-=10;}
  ShiftOut(~(chargen[DispBCD] | decimalPt));
  digitalWrite(DIGIT_3, HIGH);
  delayMicroseconds(DIGIT_TIME);
  digitalWrite(DIGIT_3, LOW);

  if (result) {
    result == DIR_CW ? frqIdx-- : frqIdx++;
    if(mode == TABLE_VALUES){
      if(frqIdx < 0) frqIdx = 33;
      if(frqIdx > 33) frqIdx = 0;
    }
    newVal = true;
  }

  ShiftOut(~(chargen[theValue]));
  digitalWrite(DIGIT_4, HIGH);
  delayMicroseconds(DIGIT_TIME);
  digitalWrite(DIGIT_4, LOW);
} // End of displayDecimal()

//-=|=-=|=-=|=-=|=-=|=-=|=-=|=-=|=-=|=-=|=-=|=-=|=-=|=-=|=-=|=-=|=-=|=-=|=-=|
// Refresh the display (perform one pass thru the multiplexor)
//   Displays a 16-bit binary integer as a 4-digit decimal value
//   Checks for encoder input while flashing each digit
//-=|=-=|=-=|=-=|=-=|=-=|=-=|=-=|=-=|=-=|=-=|=-=|=-=|=-=|=-=|=-=|=-=|=-=|=-=|
void displayInteger(int16_t theValue){
  // Convert the binary integer value into decimal digits
  // then multiplex the display using the digits
  DispBCD = 0;
  while(theValue >= 1000){DispBCD++; theValue-=1000;}
  ShiftOut(~(chargen[DispBCD]));
  digitalWrite(DIGIT_1, HIGH);
  delayMicroseconds(DIGIT_TIME);
  digitalWrite(DIGIT_1, LOW);

  unsigned char result = r.process();
  if (result) {
    result == DIR_CW ? frqIdx-- : frqIdx++;
    if(mode == TABLE_VALUES){
      if(frqIdx < 0) frqIdx = 33;
      if(frqIdx > 33) frqIdx = 0;
    }
    newVal = true;
  }

  DispBCD = 0;
  while(theValue >= 100) {DispBCD++; theValue-=100;}
  ShiftOut(~(chargen[DispBCD]));
  digitalWrite(DIGIT_2, HIGH);
  delayMicroseconds(DIGIT_TIME);
  digitalWrite(DIGIT_2, LOW);

  if (result) {
    result == DIR_CW ? frqIdx-- : frqIdx++;
    if(mode == TABLE_VALUES){
      if(frqIdx < 0) frqIdx = 33;
      if(frqIdx > 33) frqIdx = 0;
    }
    newVal = true;
  }

  DispBCD = 0;
  while(theValue >= 10)  {DispBCD++; theValue-=10;}
  ShiftOut(~(chargen[DispBCD]));
  digitalWrite(DIGIT_3, HIGH);
  delayMicroseconds(DIGIT_TIME);
  digitalWrite(DIGIT_3, LOW);

  if (result) {
    result == DIR_CW ? frqIdx-- : frqIdx++;
    if(mode == TABLE_VALUES){
      if(frqIdx < 0) frqIdx = 33;
      if(frqIdx > 33) frqIdx = 0;
    }
    newVal = true;
  }

  ShiftOut(~(chargen[theValue]));
  digitalWrite(DIGIT_4, HIGH);
  delayMicroseconds(DIGIT_TIME);
  digitalWrite(DIGIT_4, LOW);
} // End of displayInteger()

//-=|=-=|=-=|=-=|=-=|=-=|=-=|=-=|=-=|=-=|=-=|=-=|=-=|=-=|=-=|=-=|=-=|=-=|=-=|
// Refresh the display (perform one pass thru the multiplexor)
//   Displays a raw binary value as LED segments
//   Checks for encoder input while flashing each digit
//-=|=-=|=-=|=-=|=-=|=-=|=-=|=-=|=-=|=-=|=-=|=-=|=-=|=-=|=-=|=-=|=-=|=-=|=-=|
void displayRaw(uint32_t theValue){
  // Convert the binary integer value into 4 chars
  // then multiplex the display using the chars
  ShiftOut(~(theValue>>24));
  digitalWrite(DIGIT_1, HIGH);
  delayMicroseconds(DIGIT_TIME);
  digitalWrite(DIGIT_1, LOW);

  unsigned char result = r.process();
  if (result) {
    result == DIR_CW ? frqIdx-- : frqIdx++;
    if(mode == TABLE_VALUES){
      if(frqIdx < 0) frqIdx = 33;
      if(frqIdx > 33) frqIdx = 0;
    }
    newVal = true;
  }

  ShiftOut(~(theValue>>16 & 0xFF));
  digitalWrite(DIGIT_2, HIGH);
  delayMicroseconds(DIGIT_TIME);
  digitalWrite(DIGIT_2, LOW);

  if (result) {
    result == DIR_CW ? frqIdx-- : frqIdx++;
    if(mode == TABLE_VALUES){
      if(frqIdx < 0) frqIdx = 33;
      if(frqIdx > 33) frqIdx = 0;
    }
    newVal = true;
  }

  ShiftOut(~(theValue>>8 & 0xFF));
  digitalWrite(DIGIT_3, HIGH);
  delayMicroseconds(DIGIT_TIME);
  digitalWrite(DIGIT_3, LOW);

  if (result) {
    result == DIR_CW ? frqIdx-- : frqIdx++;
    if(mode == TABLE_VALUES){
      if(frqIdx < 0) frqIdx = 33;
      if(frqIdx > 33) frqIdx = 0;
    }
    newVal = true;
  }

  ShiftOut(~(theValue & 0xFF));
  digitalWrite(DIGIT_4, HIGH);
  delayMicroseconds(DIGIT_TIME);
  digitalWrite(DIGIT_4, LOW);
} // End of displayRaw()

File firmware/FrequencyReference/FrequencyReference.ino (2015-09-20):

/**************************************************************************/
/*!
    @file     FrequencyReference.ino
    @author   C. Schnarel
	@license  BSD (see license.txt)

    Application firmware for the Frequency Reference hardware.
       Rotary encoder UI, USB remote control, 7-segment display, and
       programmable divider (timer/counter1) that divides the system clock
       providing a selectable frequency, 50% duty cycle square-wave output.

    @section  HISTORY

    2015-Sep-16  - First public release, C. Schnarel
*/
/**************************************************************************/

/*
  To get F_CPU = 20000000L make appropriate changes to boards.txt
  in the Arduino IDE.  See README in firmware folder.
*/

// Include libraries this sketch will use
//#include <ProfileTimer.h>
//#include <SPI.h>
//#include <EEPROM.h>
#include <Rotary.h>         // https://github.com/brianlow/Rotary
#include <Bounce.h>         // http://playground.arduino.cc/Code/Bounce
#include <Timer1.h>         // in firmware folder

// Pins to drive Segment Shift Register
#define SR_DATA A0
#define SR_CLK A1

// Serial interface pins (defined in serial lib)
//#define RCV 0
//#define XMT 1

// UI Rotary Encoder w Button
#define BUTTON 4
#define DEBOUNCE_TIME 5
// Encoder interface pins (used in rotary instantiation)
#define ROT_A 3
#define ROT_B 2

// Display digit pins
#define DIGIT_1 8
#define DIGIT_2 7
#define DIGIT_3 6
#define DIGIT_4 5

// Battery level measurement
#define BATT_SENSE A2

// Frequency Signal Out
#define F_OUT 9


// This sets the delay time for frame rate
// The value is repeated for each of the digits on the display so
//   frame rate = 1 / (4 * DIGIT_TIME(uS)) -> 125 Hz
#define DIGIT_TIME 2000

// Mode values
// choose a predefined frequency from a table of values
#define TABLE_VALUES true
// send the divisor value directly to the divider
#define DIVISOR false

// Segments scrambled
//   to ease PCB layout
//   PC={G,D,A,B,E,C,Dp,F}
#define DP 0x02
// Character generator for 7-segment displays
uint8_t	chargen[] = {
  0b01111101,  // 0  '0'
  0b00010100,  // 1  '1'
  0b11111000,  // 2  '2'
  0b11110100,  // 3  '3'
  0b10010101,  // 4  '4'
  0b11100101,  // 5  '5'
  0b11101101,  // 6  '6'
  0b00110100,  // 7  '7'
  0b11111101,  // 8  '8'
  0b11110101,  // 9  '9'
  0b10111101,  // 10  'A'
  0b11001101,  // 11  'B'
  0b01101001,  // 12  'C'
  0b11011100,  // 13  'D'
  0b11101001,  // 14  'E'
  0b10101001,  // 15  'F'
  0b00000000   // 16  ' '
};

// Lookup table for generating common frequencies
#define TABLE_LENGTH 38
static uint16_t commonFreq[] = {
  64246,  //        155.649
  49999,  //        200
  39999,  //        250
  24999,  //        400
  19999,  //        500
  15999,  //        625
  12499,  //        800
  9999,   //      1,000
  7999,   //      1,250
  4999,   //      2,000
  3999,   //      2,500
  3199,   //      3,125
  2499,   //      4,000
  1999,   //      5,000
  1599,   //      6,250
  1249,   //      8,000
  999,    //     10,000
  799,    //     12,500
  499,    //     20,000
  399,    //     25,000
  249,    //     40,000
  199,    //     50,000
  159,    //     62,500
  124,    //     80,000
  99,     //    100,000
  79,     //    125,000
  49,     //    200,000
  39,     //    250,000
  31,     //    312,500
  24,     //    400,000
  19,     //    500,000
  15,     //    625,000
  9,      //  1,000,000
  7,      //  1,250,000
  4,      //  2,000,000
  3,      //  2,500,000
  1,      //  5,000,000
  0,      // 10,000,000
};

// Lookup table for display values that go with common frequencies
static uint16_t dispFreq[] = {
  156,      //        155.65
  200,      //        200
  250,      //        250
  400,      //        400
  500,      //        500
  625,      //        625
  800,      //        800
  1000,      //      1,000
  1250,      //      1,250
  2000,      //      2,000
  2500,      //      2,500
  3125,      //      3,125
  4000,      //      4,000
  5000,      //      5,000
  6250,      //      6,250
  8000,      //      8,000
  100,      //     10,000
  125,      //     12,500
  200,      //     20,000
  250,      //     25,000
  400,      //     40,000
  500,      //     50,000
  625,      //     62,500
  800,      //     80,000
  1000,      //    100,000
  1250,      //    125,000
  2000,      //    200,000
  2500,      //    250,000
  3125,      //    312,500
  4000,      //    400,000
  5000,      //    500,000
  6250,      //    625,000
  1000,      //  1,000,000
  1250,      //  1,250,000
  2000,      //  2,000,000
  2500,      //  2,500,000
  5000,      //  5,000,000
  1000,      // 10,000,000
};

// Instantiate objects used in this project
Rotary r = Rotary(ROT_A, ROT_B);
Bounce button = Bounce(BUTTON, DEBOUNCE_TIME);
Timer1 freqDivider = Timer1();

boolean startup = true;
unsigned long startTime = 0;
uint8_t CmdArray[10];
uint8_t CmdArrayIdx = 0;
int32_t frqIdx = 0;
uint8_t sdata = 0;
int DispBCD = 0;
boolean newVal = true;
boolean batt_lo = false;
boolean mode = DIVISOR;

//-=|=-=|=-=|=-=|=-=|=-=|=-=|=-=|=-=|=-=|=-=|=-=|=-=|=-=|=-=|=-=|=-
// system startup and initialization
//-=|=-=|=-=|=-=|=-=|=-=|=-=|=-=|=-=|=-=|=-=|=-=|=-=|=-=|=-=|=-=|=-
void setup() {
  // Initialize USB interface
  Serial.begin(9600);
  //delay(2000);
  Serial.println("Reference Frequency Generator @ 20 MHz");

  // set up sense pins
  pinMode(BATT_SENSE, INPUT);

  // set up the button input pin
  pinMode(BUTTON, INPUT_PULLUP);

  // set up the display SR control pins
  pinMode(SR_DATA, OUTPUT);
  pinMode(SR_CLK, OUTPUT);

  // set up the digit control pins
  pinMode(DIGIT_1, OUTPUT);
  pinMode(DIGIT_2, OUTPUT);
  pinMode(DIGIT_3, OUTPUT);
  pinMode(DIGIT_4, OUTPUT);

  // set up frequency output pin
  pinMode(F_OUT, OUTPUT);

  // now do the startup dance to check the display & LEDs
  startup = true;
  startTime = millis() + 5000;
  while (startup) startLoop();

  // WARNING: CAN'T USE PWM (analog out) AFTER THIS
  freqDivider.begin();  // Set up counter 1 to be frequency divider

} // End of setup()
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

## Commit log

2015-09-01 Initial Commit of schematic & board
    Complete design, but not necessarily final.
    [FreqStd.brd, FreqStd.sch]
2015-09-03 Rev A board as ordered
    Minor changes for ordering. Added OSHPark renderings. Started writing
    firmware and GitHub cover.
    [FreqStd.brd, FreqStd.sch]
2015-09-03 Start of Rev-B
    Change name to FrequencyReference.
    Added part num to BNC connector.
    [BOM.xlsx, FreqRef.brd, FreqRef.csv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]
2015-09-03 README edits
    fixed board render sizes
2015-09-04 More documentation work
    [BOM.xlsx]
2015-09-07 More docs. Rev-B layout. Debugged sketch.
    Continue documentation. Added two oscillator options to PCB schematic
    and layout. Debugged sketch on Redboard.
    [AlternateXOs.xlsx, FreqRef.brd, FreqRef.sch]
2015-09-16 Software debug. Schematic values. Added photos.
    [FreqRef.brd, FreqRef.sch]
2015-09-16 Syncing links. Updating BOM.
    [BOM.xlsx, RevA BOM.xlsx]
2015-09-16 Added library attributions and release dates.
    [RevA BOM.xlsx]
2015-09-16 PNG Format schematic and layout.
2015-09-20 Code formatting changes. A couple more OCXOs.
    [AlternateXOs.xlsx]
2015-10-12 Investigated a couple more XOs
    [AlternateXOs.xlsx]

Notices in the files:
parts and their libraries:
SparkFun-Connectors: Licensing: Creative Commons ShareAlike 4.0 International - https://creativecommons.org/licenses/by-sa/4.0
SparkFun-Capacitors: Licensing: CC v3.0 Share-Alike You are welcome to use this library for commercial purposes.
